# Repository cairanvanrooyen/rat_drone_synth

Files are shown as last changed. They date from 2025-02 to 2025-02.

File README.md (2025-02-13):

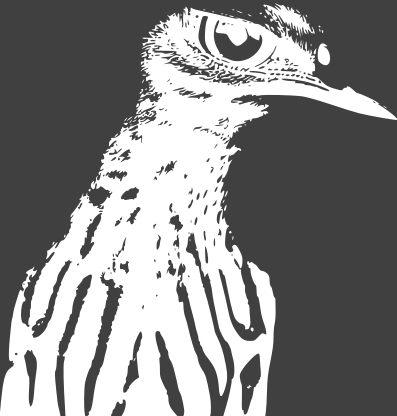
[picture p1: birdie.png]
Title


# The 'RAT' Drone Synth

This repository describes my RAT (reverse avalanche transistor) drone synth. I generated the image of the bird using Stable Diffusion (AI).

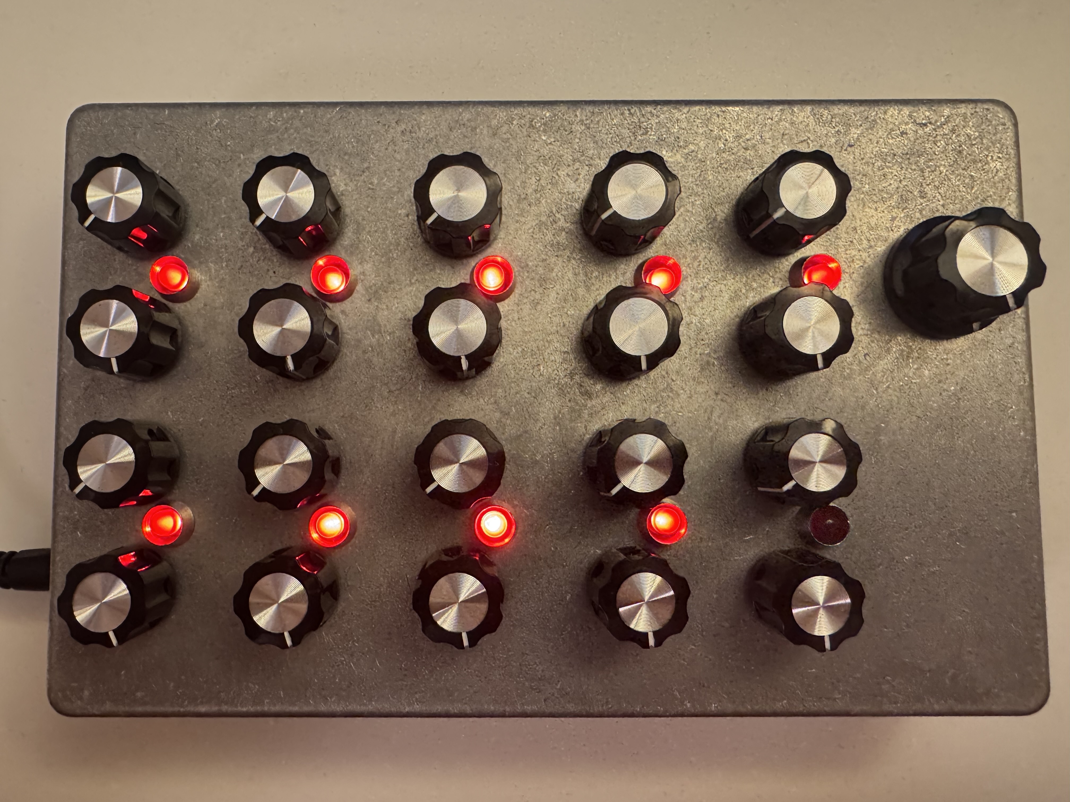
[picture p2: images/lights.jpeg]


> [!CAUTION]
> This repository is provided for information only. I am not an electronic or electrical engineer, and so, if you decide to build this project, you do so at your own risk.

## Introduction and inspiration

This project was inspired by the work by [Sam Battle](https://www.lookmumnocomputer.com/bio) of [Look Mum No Computer](https://www.lookmumnocomputer.com/). Sam released a video where he made a synthesiser from a Red Bull can - [watch it here](https://www.youtube.com/watch?v=WjrJeUBjw5g&t=1s). In his related post ['Super simple oscillator'](https://www.lookmumnocomputer.com/simplest-oscillator) he described more of the electronics and a few example schematics. There was also a link to a more technical description of reverse avalanche mode on a blog [BJT In Reverse Avalanche Mode by Kerry D. Wong](http://www.kerrywong.com/2014/03/19/bjt-in-reverse-avalanche-mode/). It was through both Sam's and Kerry's websites that I learned more about the SS9018 and became inspired to make a drone synth.

[This page by 'Pixmusix'](https://core-electronics.com.au/projects/analogue-quad-oscillator-drone-synth/) is perhaps the best I have found so far on this type of oscillator, [its history](https://www.analog.com/media/en/technical-documentation/application-notes/an72f.pdf), how it works and some nice working examples. Pix also provide a very nice animation of this circuit in action. 

## The design

My design is an adapted version of Sam Battle's ['2000 Megadrone Module'](https://www.lookmumnocomputer.com/2000-megadrone). There are schematics and a BOM on his website.

I adapted the design - removed CV, eurorack power and adapted the capacitors to generally be lower in value and therefore lower in pitch.

If you want to build this yourself, you should explore different capacitor values to suit your tastes. I chose 100uF (low), 10uF (mid) and 4.7uF (high). Although if i built another, i might include more variety.

> [!NOTE]
> Vary the capacitors according to your taste. I used 100uF, 10uF and 4.7uF - this is different to the schematic.

The design includes 10 oscillators, each with their own pitch and volume control. Finally, there is a master tone control (a kind of low pass filter). The unit is powered by a 12V DC (2.5mm) male power adaptor.

> [!WARNING]
> I messed up the potentiometer connections and so the pots work in reverse, which is kind of interesting and fits with the whole reverse theme of the synth. Some people may be annoyed or not like this - proceed at your own risk.

I designed the schematic and PCB in [KiCAD](https://www.kicad.org/) - which is incredible and its free! My schematic, PCB and drill templates are included in this repository.

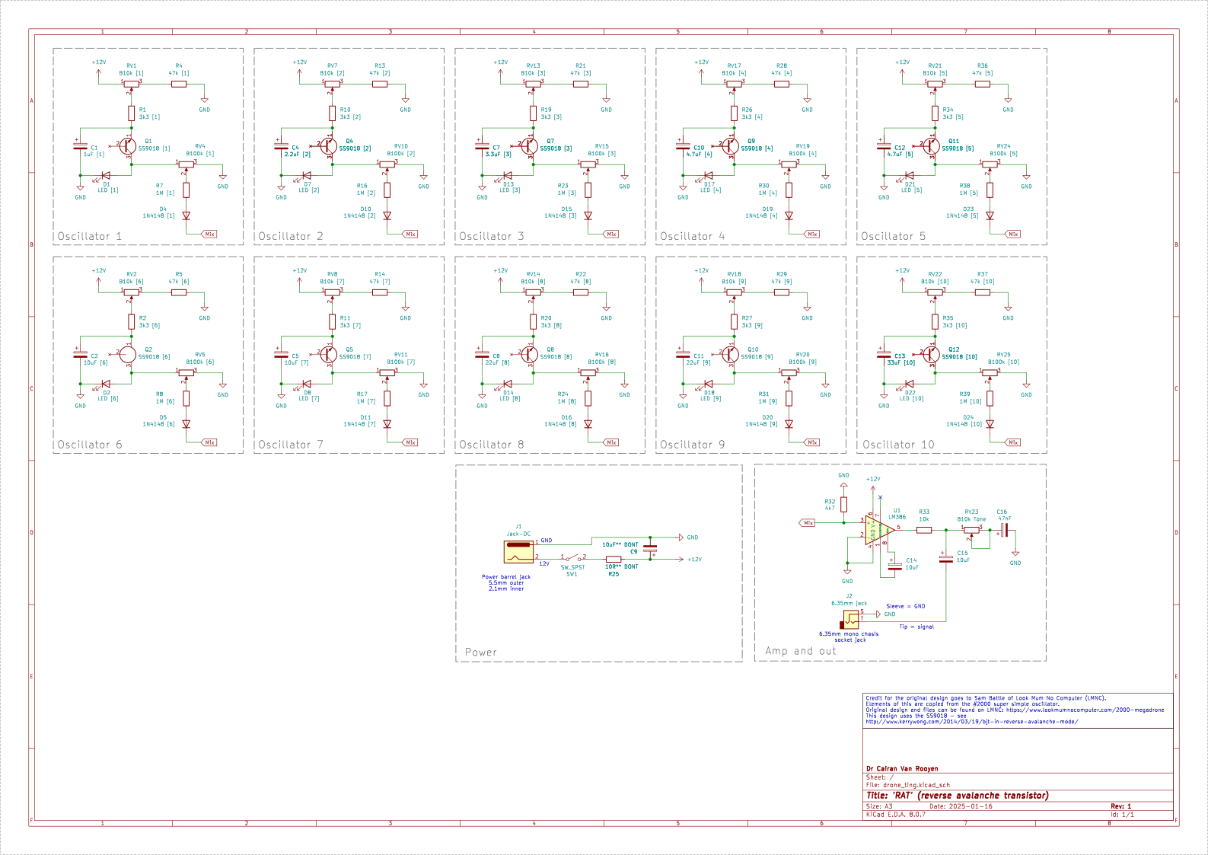
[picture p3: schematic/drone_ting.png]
Schematic


## The PCB

The PCB is simple, 2 sided with pots and LEDs on one side and all other components on the other. I had mine made by [JLCPCB](https://jlcpcb.com/), costing $11.40 + postage - for 5! If you want to order the same for yourself - navigate to the \gerbers\send_to_PCB_manufacturer.zip - simply upload this to your chosen manufacturer to order.

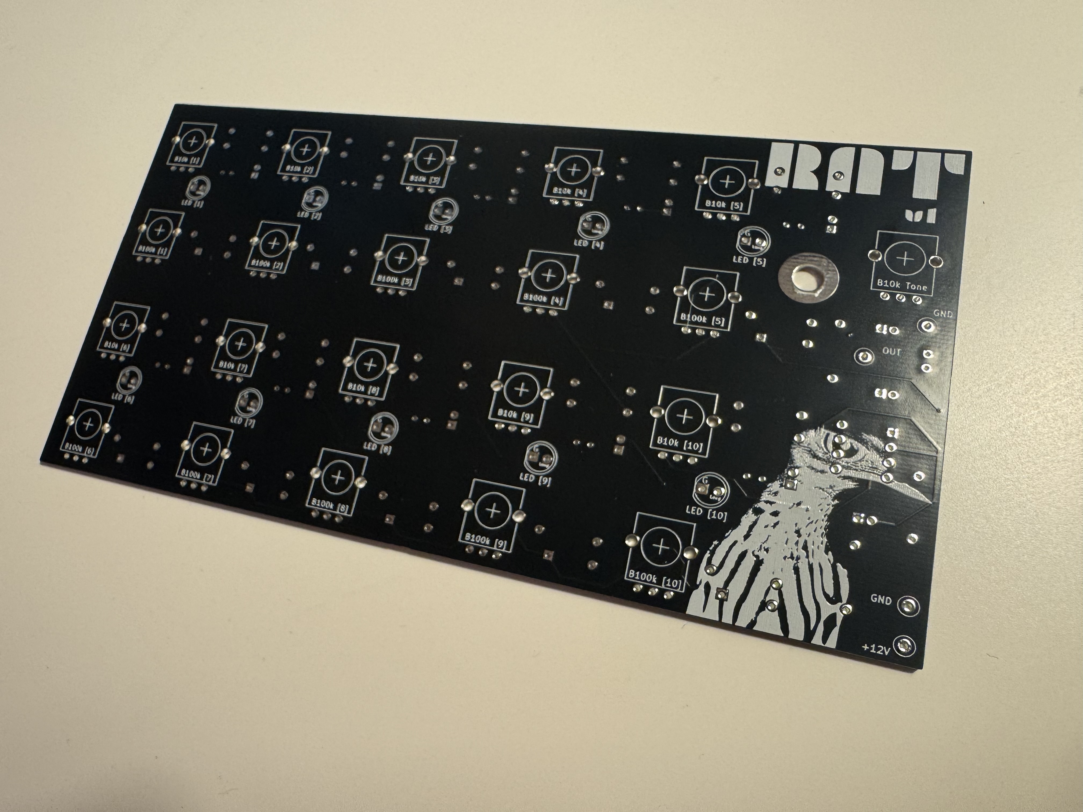
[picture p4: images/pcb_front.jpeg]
PCB front

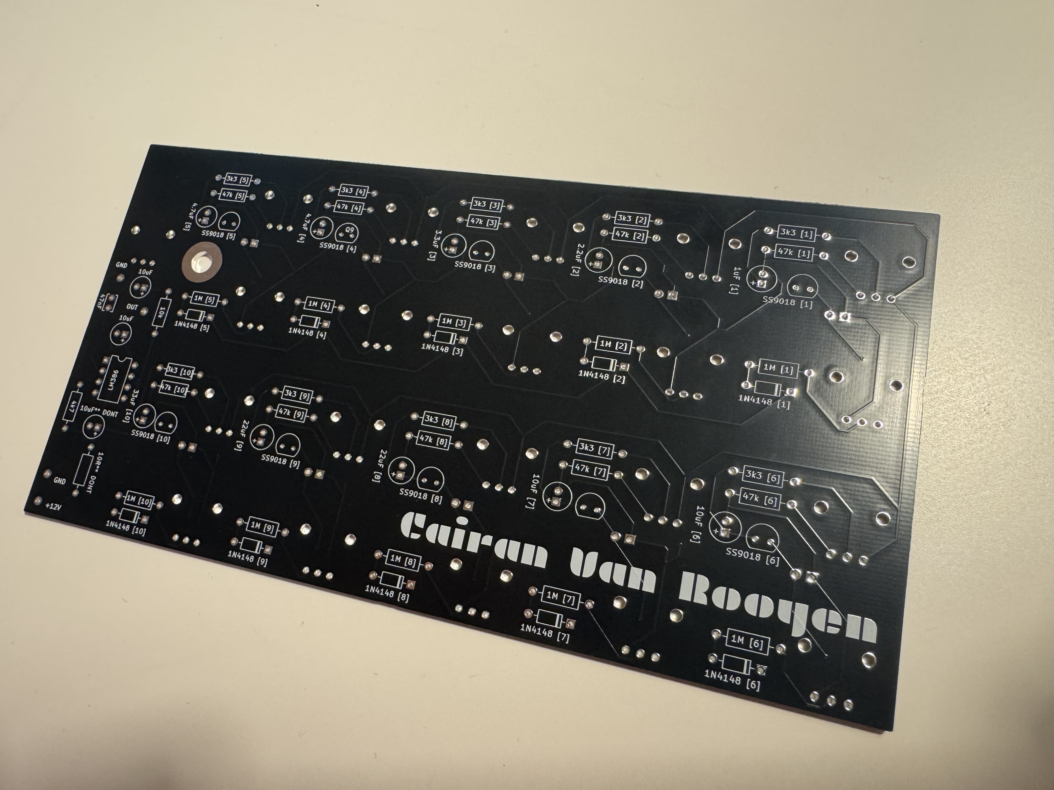
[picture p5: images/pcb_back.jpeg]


This is a very beginner friendly build, all through hole components and nothing too small.

## Bill Of Materials

I used Tayda to source all my components, apart from the 10x SS9018, which i sourced from e-Bay (£7.95 + postage).

- [Fairchild SS9018 VHF RF Bipolar Transistor](https://www.onsemi.com/download/data-sheet/pdf/ss9018-d.pdf)
- [LM386](https://www.taydaelectronics.com/lm386-audio-amplifier-1-channel-mono-class-ab-325mwx1at8-ohm-4v-12v-pdip-8.html)
- [100K OHM Linear Taper Potentiometer Round Shaft PCB 9mm](https://www.taydaelectronics.com/100k-ohm-linear-taper-potentiometer-round-shaft-pcb-9mm.html)
- [10K OHM Linear Taper Potentiometer Round Shaft PCB 9mm](https://www.taydaelectronics.com/10k-ohm-linear-taper-potentiometer-round-shaft-pcb-9mm.html)
- [KN1360 ABS Fluted Black Knob 16x12mm](https://www.taydaelectronics.com/kn1360-knob-black.html) - these are for the volume and tone knobs for each oscillator. I used a slightly larger knob for the master tone.
- [REAN Neutrik NYS229 6.35mm 1/4" Mono Chassis Socket](https://www.taydaelectronics.com/neutrik-6-35mm-1-4-mono-chassis-socket-jack.html)
- [DC Power Jack 2.5mm Panel Mount Round DC-099](https://www.taydaelectronics.com/dc-power-jack-2-5mm-x-5-5-mm-round-type-panel-mount-dc-099.html)
- [5mm Bezel LED Holder Chrome Metal](https://www.taydaelectronics.com/5mm-bezel-led-holder-chrome-metal.html)
- [LED 5mm Red Super Bright](https://www.taydaelectronics.com/led-5mm-red.html)
- Example capacitor: [10uF 50V 105C Radial Electrolytic Capacitor 5x11mm](https://www.taydaelectronics.com/10uf-50v-105c-radial-electrolytic-capacitor-5x11mm.html)
- All resistors: [1/4W 1% metal film](https://www.taydaelectronics.com/resistors/1-4w-metal-film-resistors/test-group-2.html)
- [1N4148 Switching Signal Diode](https://www.taydaelectronics.com/1n4148-switching-signal-diode.html)
- [1 small ceramic disk capacitor](https://www.taydaelectronics.com/capacitors/ceramic-disc-capacitors/test-group-2.html)

## The enclosure

I wanted an 80's industrial submarine type vibe to suit the very heavy and industrial sounds that this drone synth can produce. I opted for a [1590DD Style Aluminum Diecast Enclosure from Tayda](https://www.taydaelectronics.com/1590dd-style-aluminum-diecast-enclosure.html). I also got them to do all the [custom drilling](https://www.taydaelectronics.com/1590dd-custom-drill-enclosure-service.html) on the front. I have included the drilling template in the KiCAD files. Screenshot of this below:

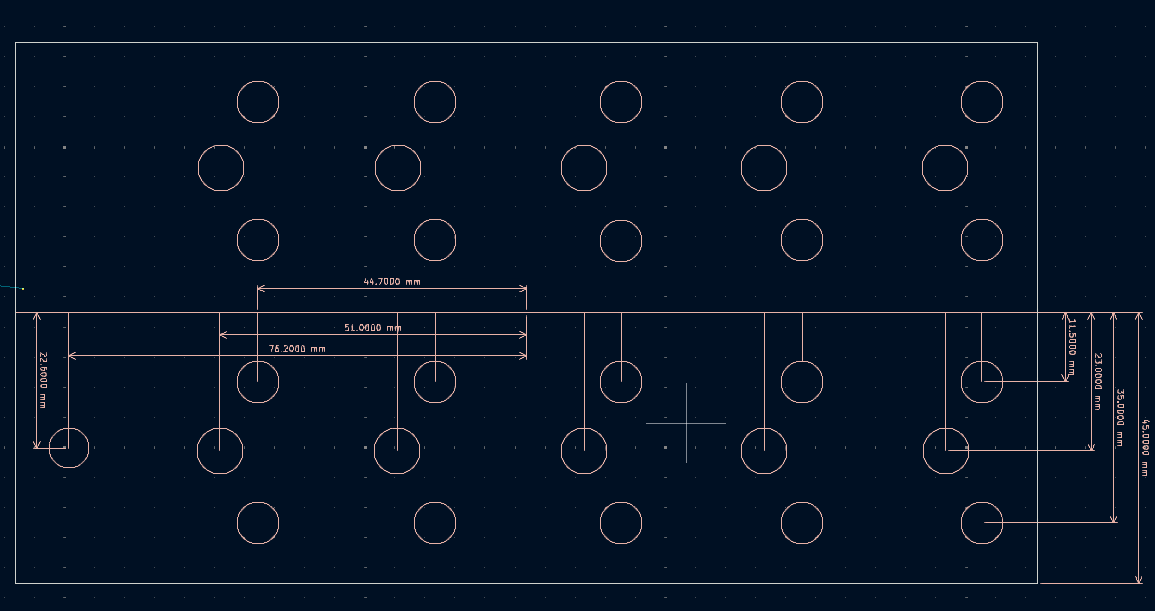
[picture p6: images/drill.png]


## The finished article

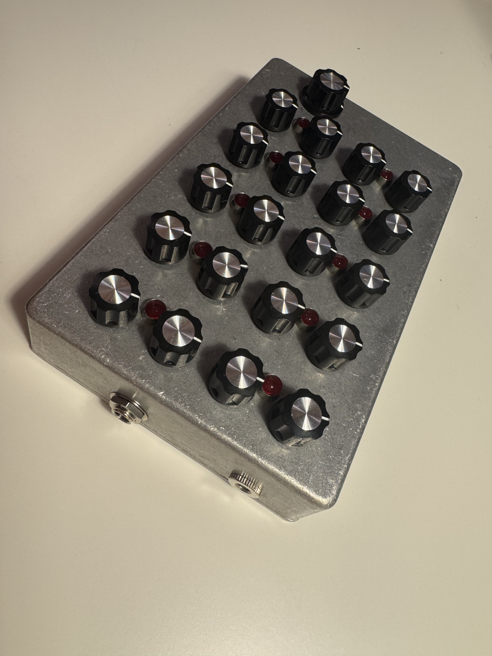
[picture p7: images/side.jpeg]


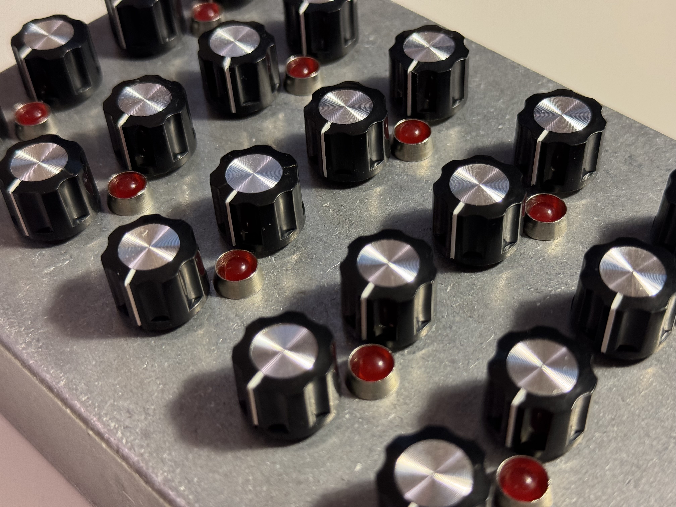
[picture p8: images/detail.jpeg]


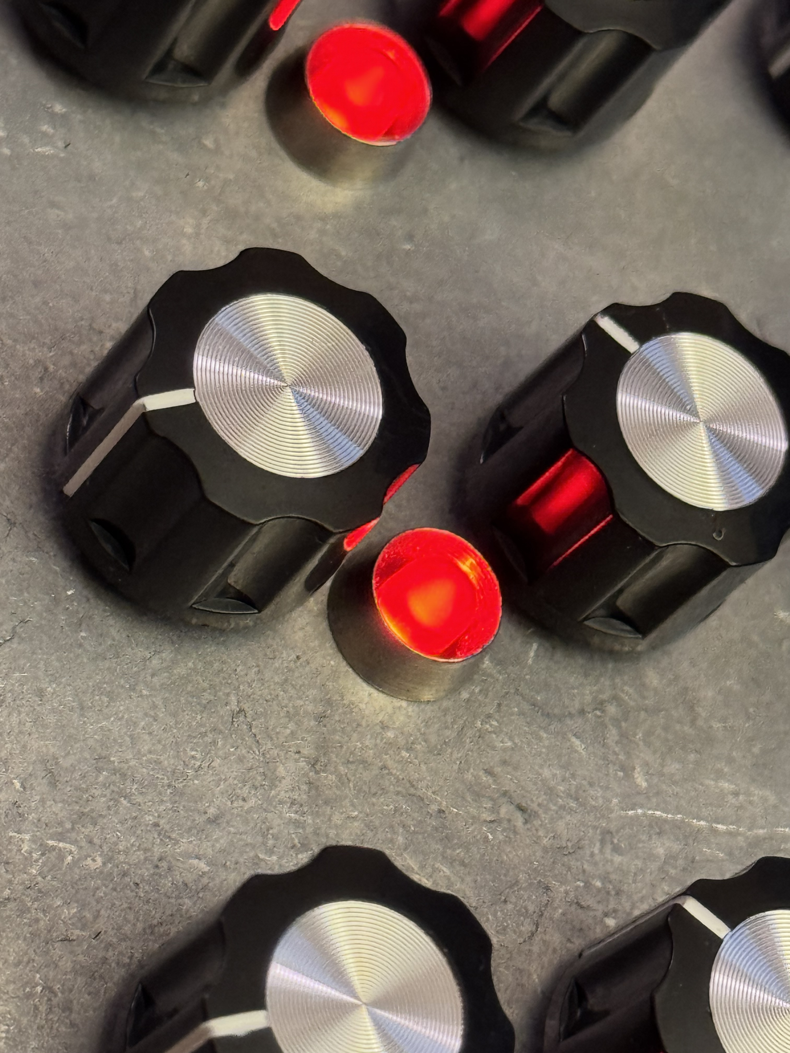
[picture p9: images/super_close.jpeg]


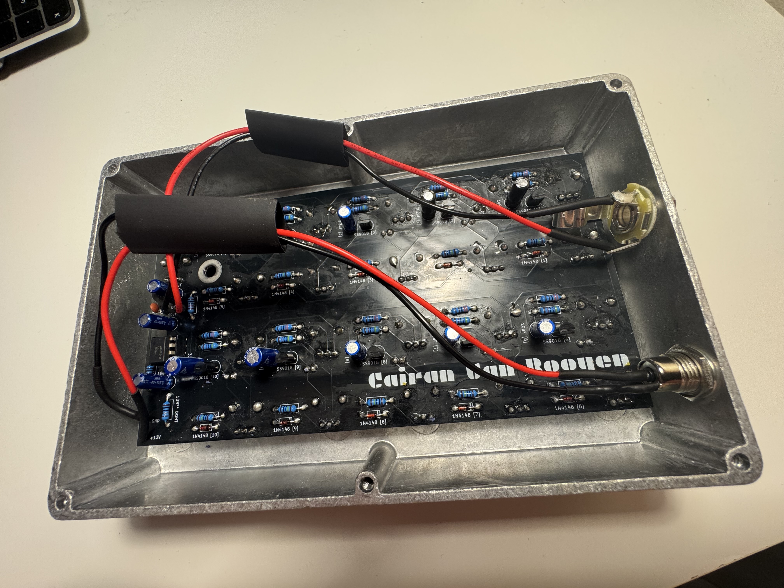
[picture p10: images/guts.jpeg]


It turned out to be exactly how I imagined. I have contemplated laser etching some labels and things onto the synth front, but I actually like the fact that its clean and blank and is intriguing. It is after all, an incredibly simple instrument to use.

## 'Technical' audio demo

Below is an image of the waveform of one 10uF oscillator. 

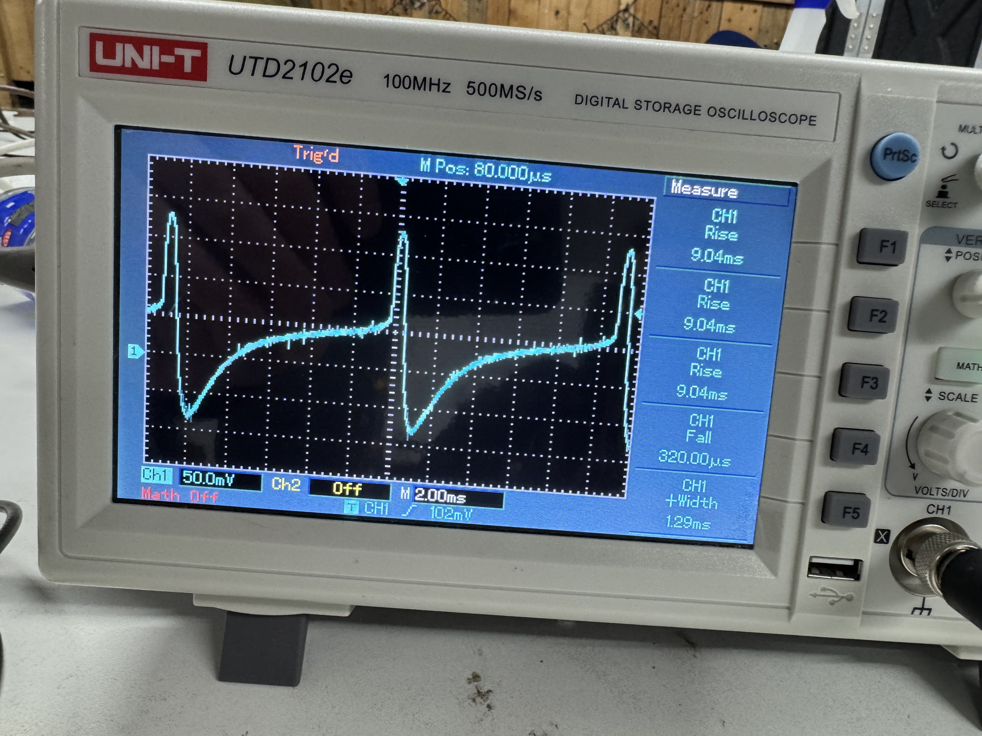
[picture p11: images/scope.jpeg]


I also recorded a video where I connected the synth to my Focusrite Scarlett Solo, passed into Ableton Live and used Pro-Q3 and [jo.Floating Oscilloscope 1.1](https://maxforlive.com/library/device/1918/jo-floating-oscilloscope) - see screenshot below. In the video, I slowly bring in each of the different (4.7uF, 10uF and 100uF oscillators) and change their volume and pitch. Pro-Q3 shows the frequency form of the sound and the oscilloscope (although not ideal) gives some idea of the waveform. The video can be accessed [here on YouTube](https://youtu.be/z13XVZWmLFw).

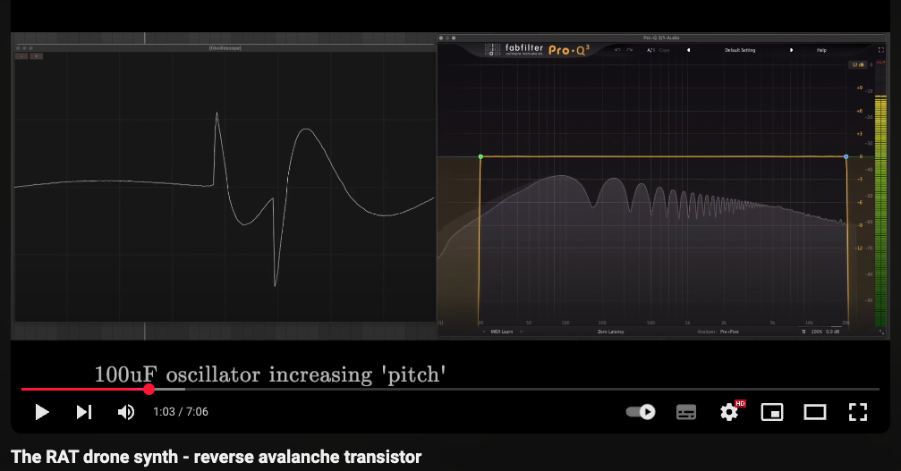
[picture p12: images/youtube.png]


## Sound demo

[Click here for sound demo](https://github.com/cairanvanrooyen/rat_drone_synth/blob/main/demo.wav)

## Lessons learned and future ideas

1. Get the pots the right way around ;)
2. Maybe have a cutout section in PCB to allow for power and audio jacks
3. More variety in capacitor values
4. Get Tayda to drill power and audio
5. Maybe laser etch the face
6. More additions: distortion, delay, wavefolder, on/off switches, CV, LFO, switching different caps and more...

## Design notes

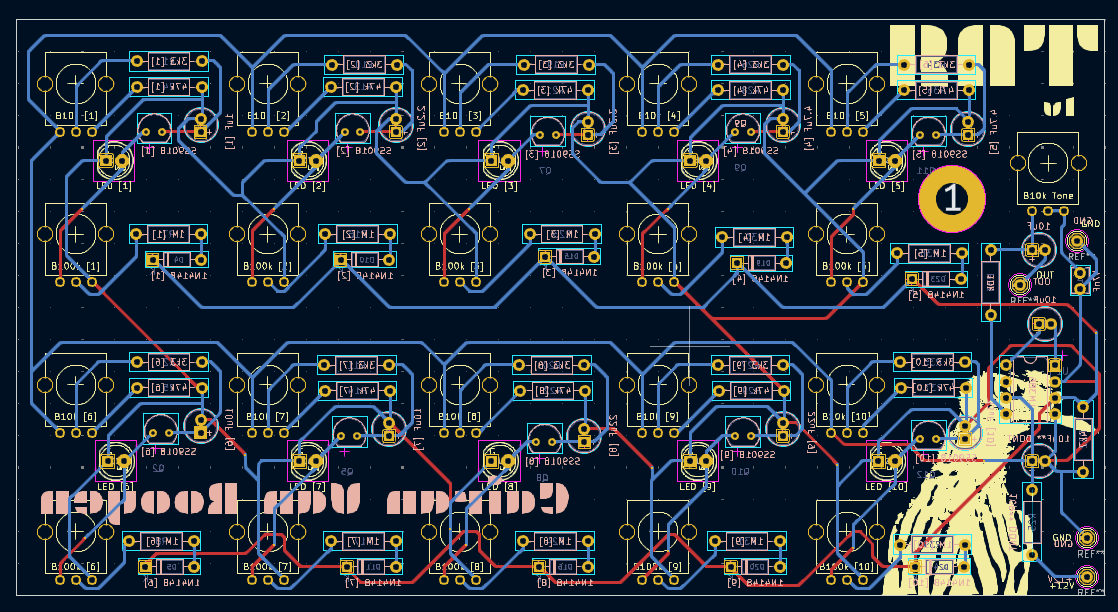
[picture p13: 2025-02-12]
images/pcb.png

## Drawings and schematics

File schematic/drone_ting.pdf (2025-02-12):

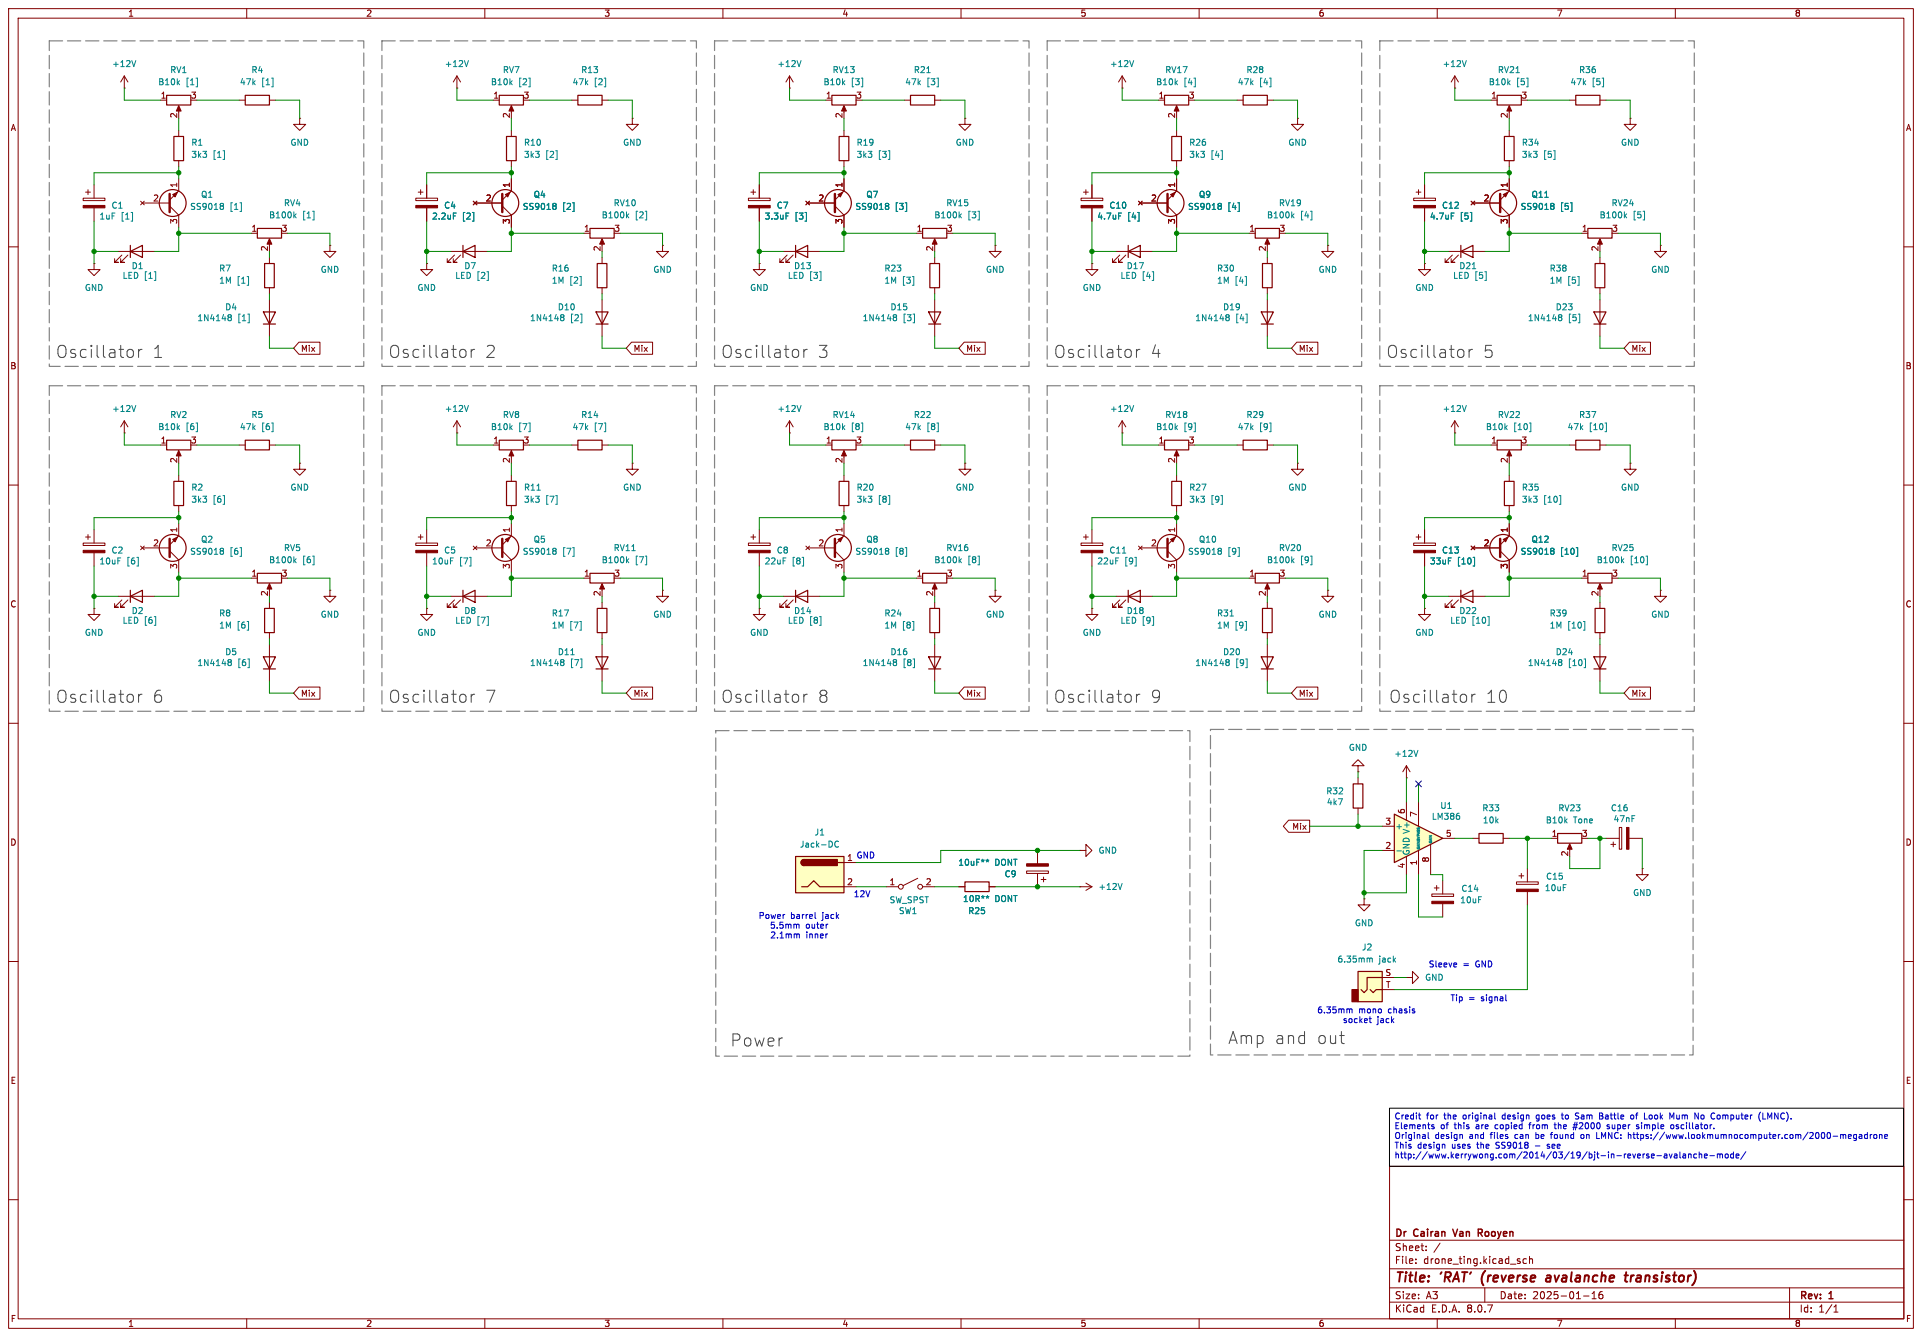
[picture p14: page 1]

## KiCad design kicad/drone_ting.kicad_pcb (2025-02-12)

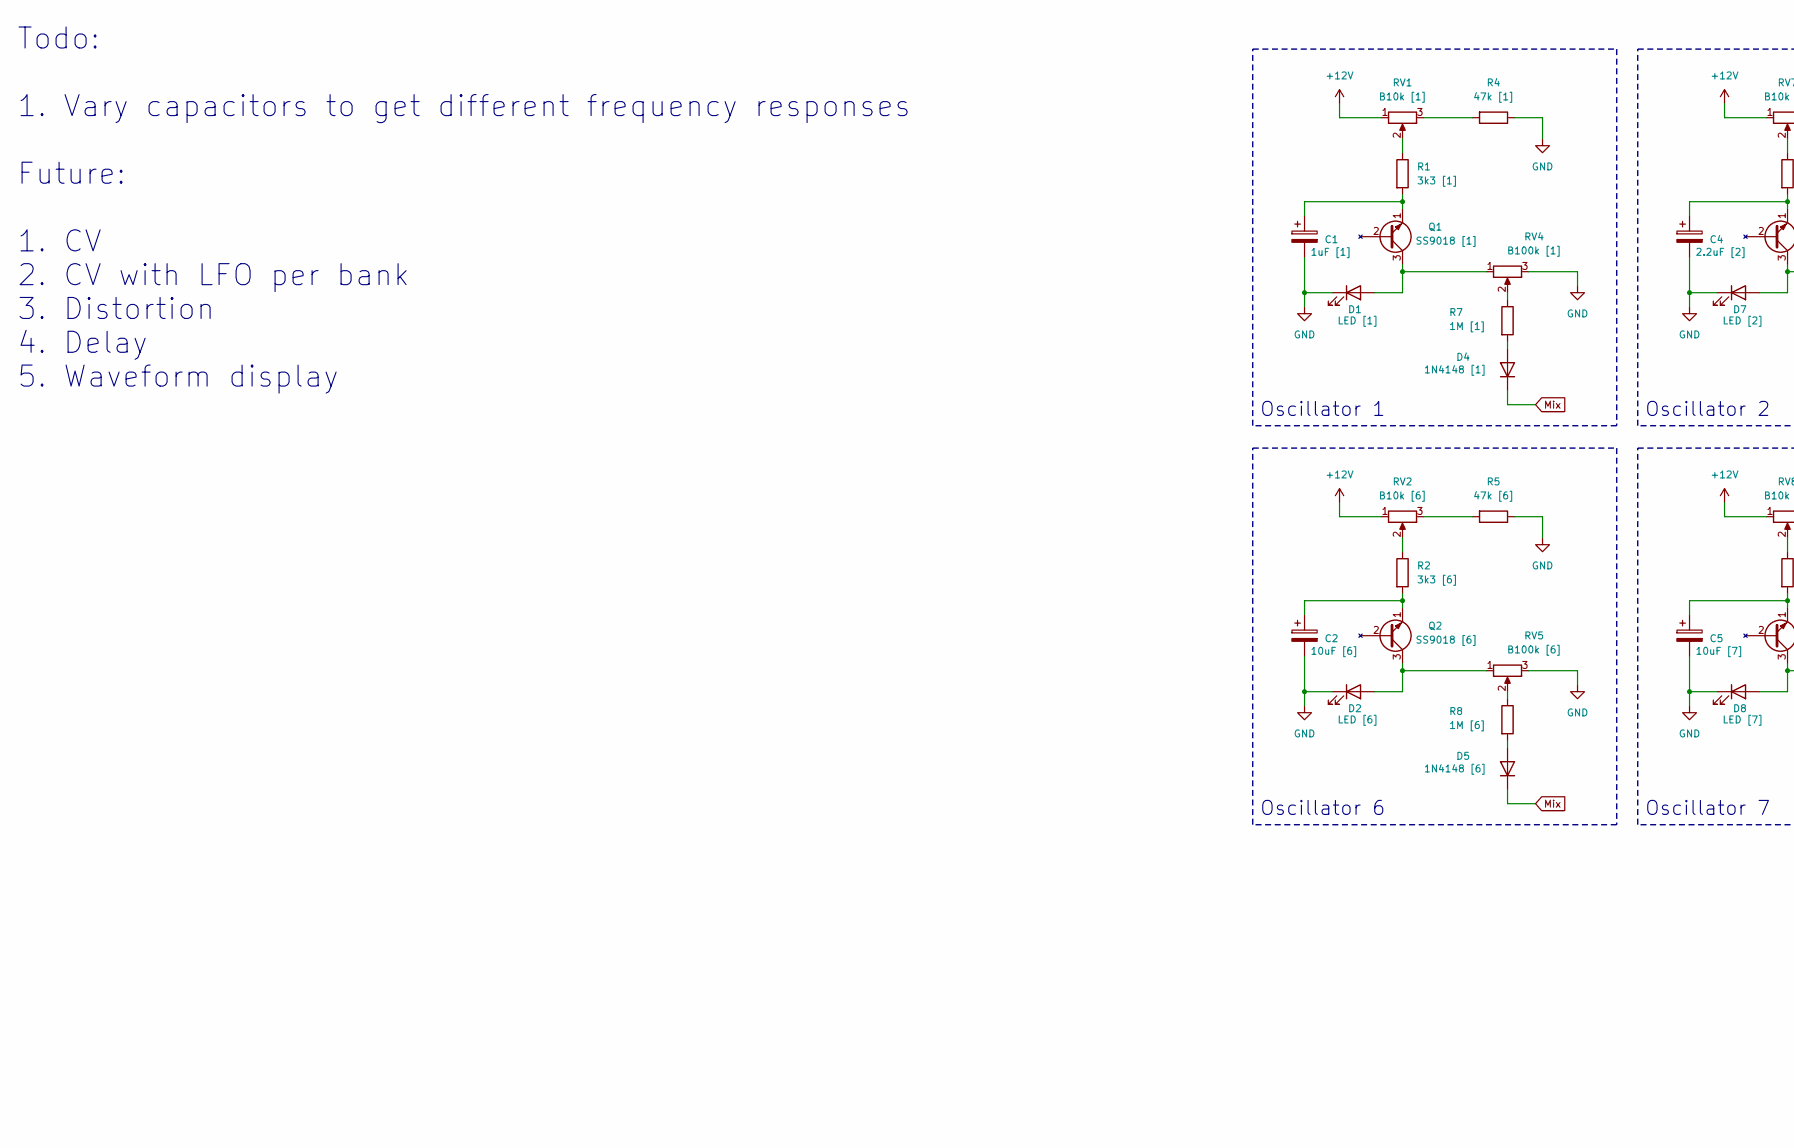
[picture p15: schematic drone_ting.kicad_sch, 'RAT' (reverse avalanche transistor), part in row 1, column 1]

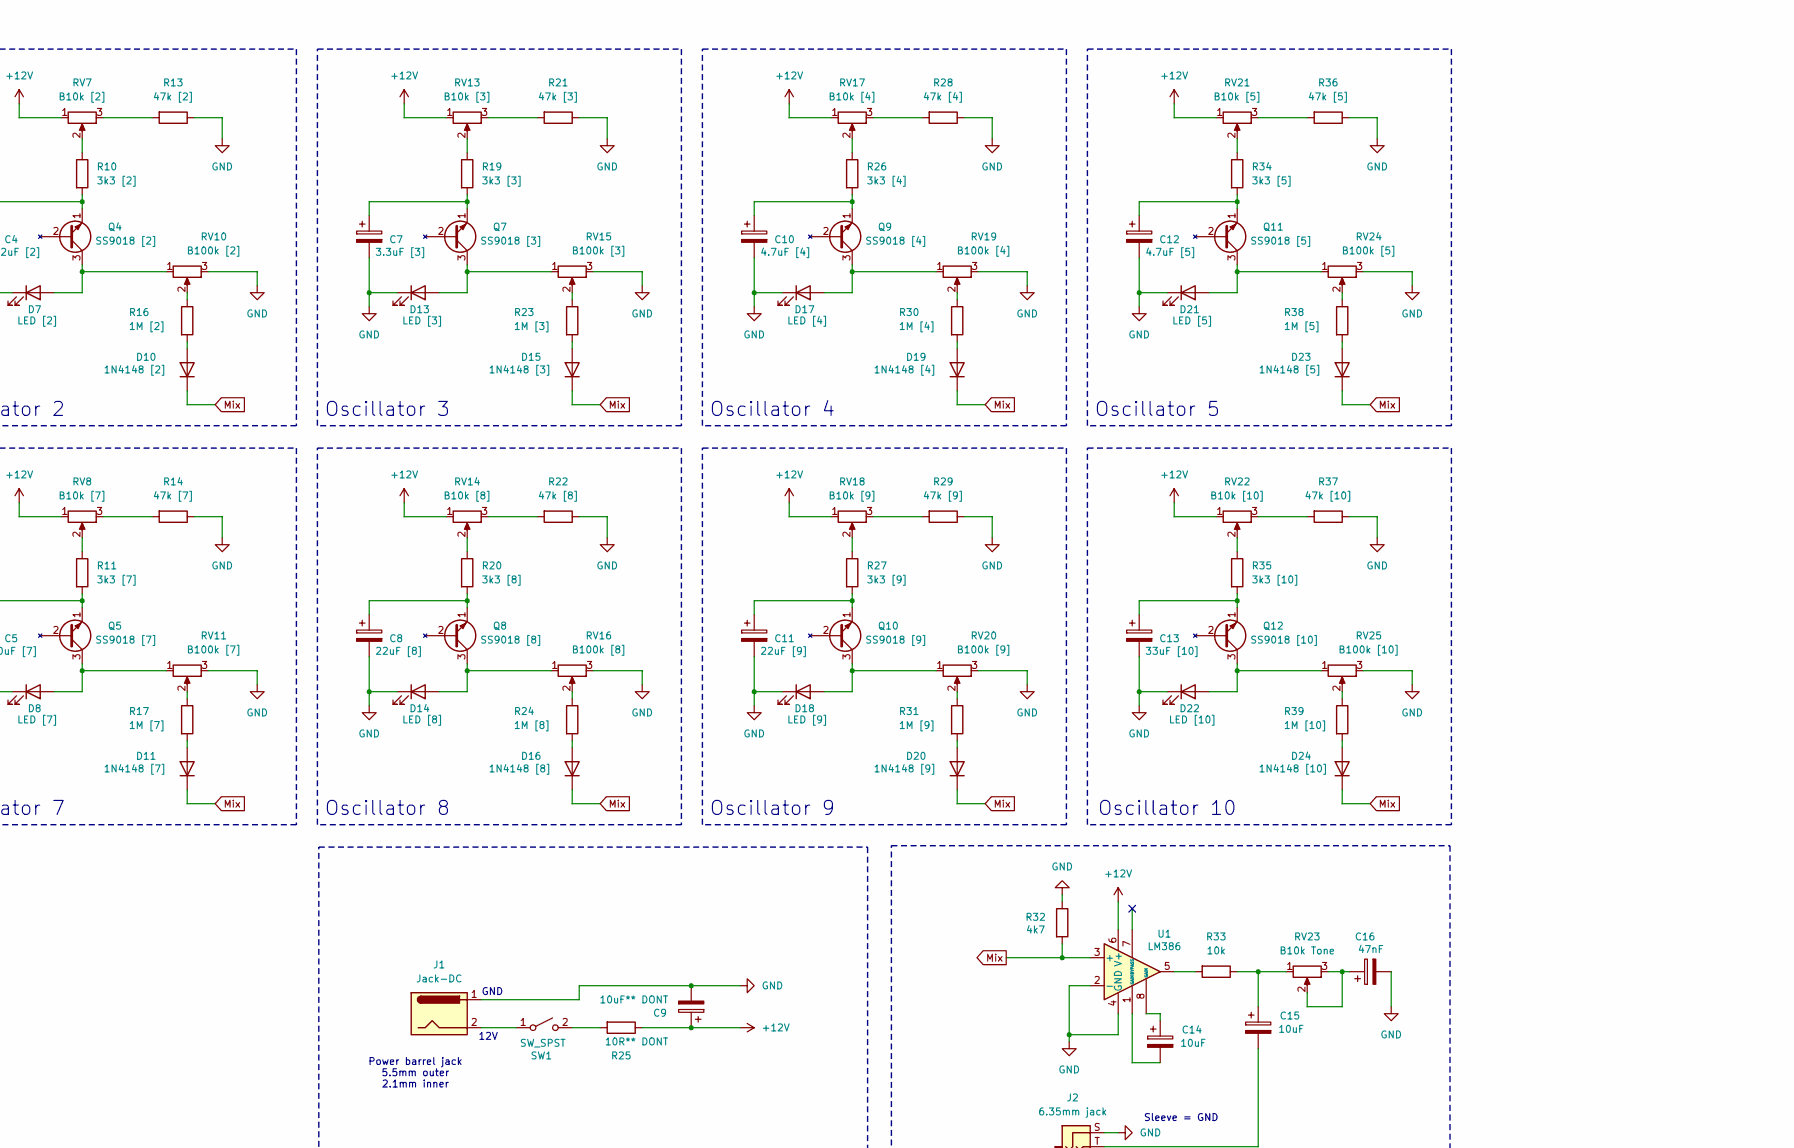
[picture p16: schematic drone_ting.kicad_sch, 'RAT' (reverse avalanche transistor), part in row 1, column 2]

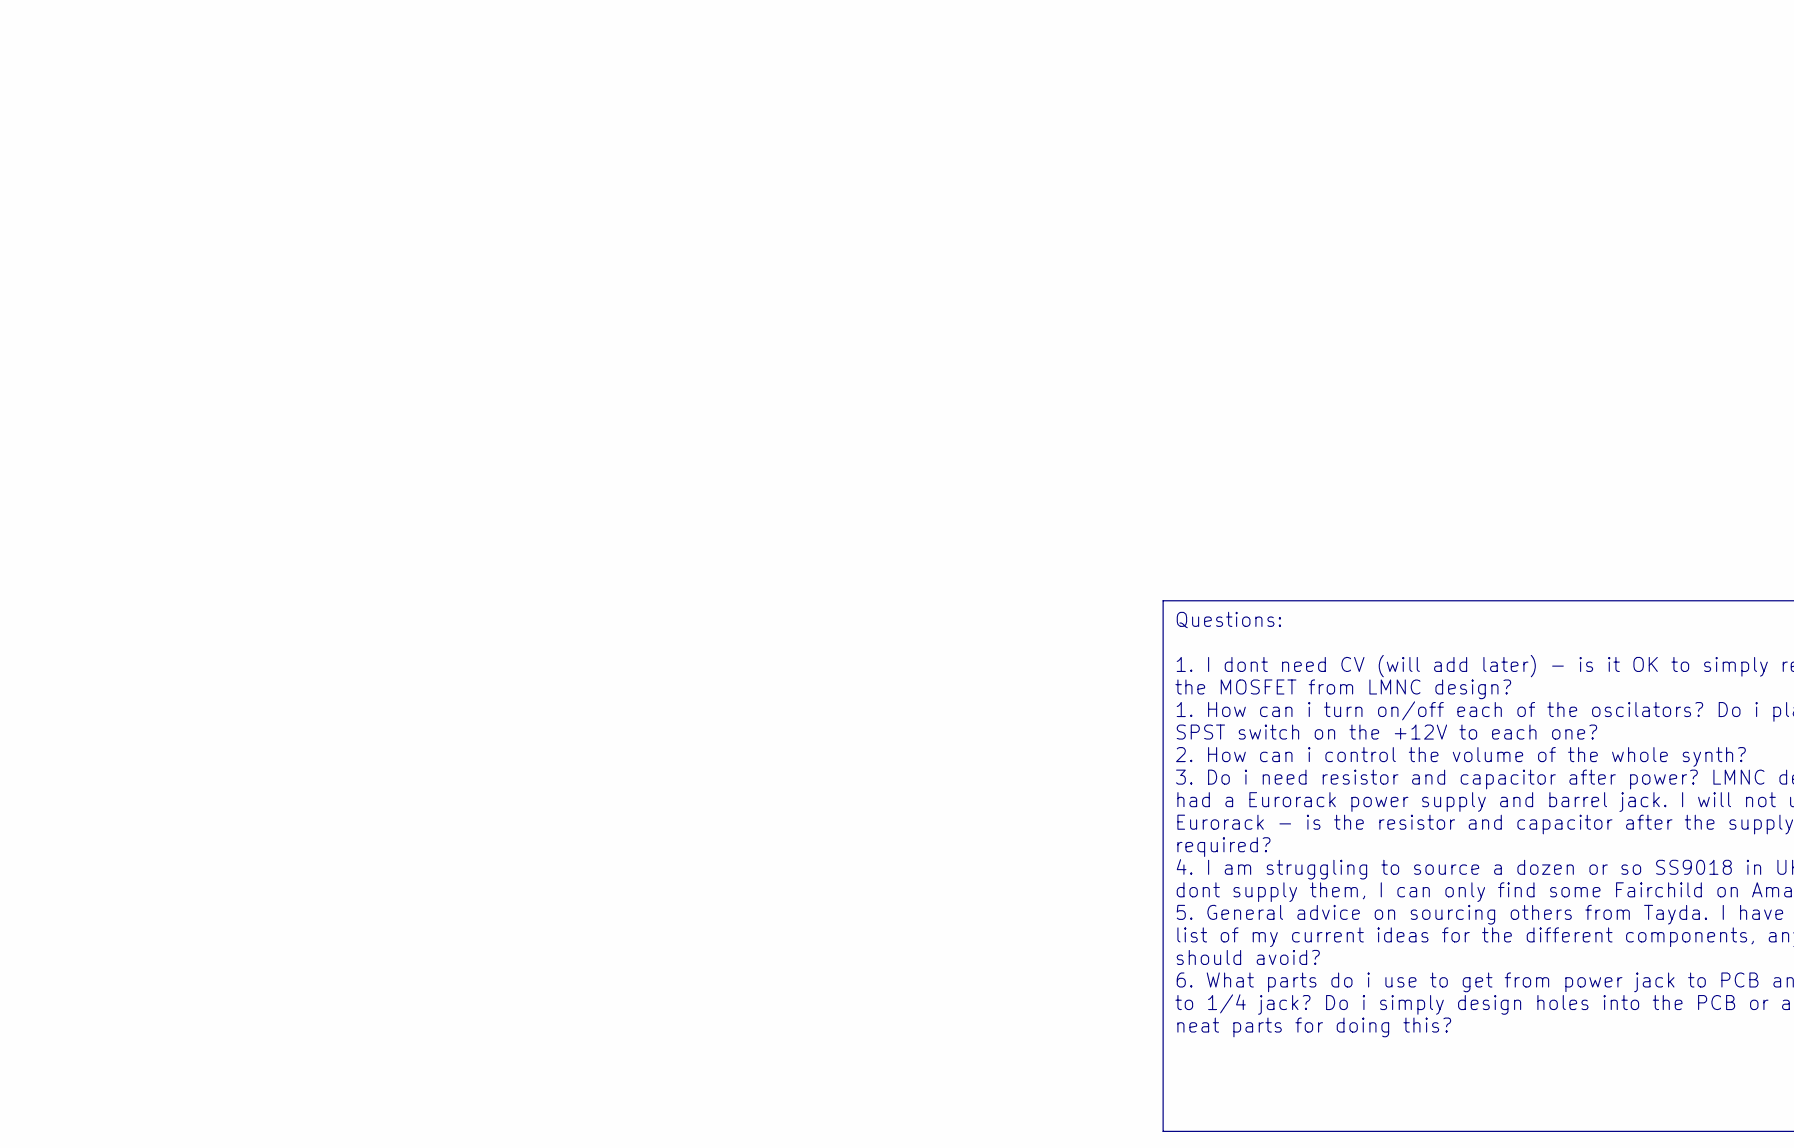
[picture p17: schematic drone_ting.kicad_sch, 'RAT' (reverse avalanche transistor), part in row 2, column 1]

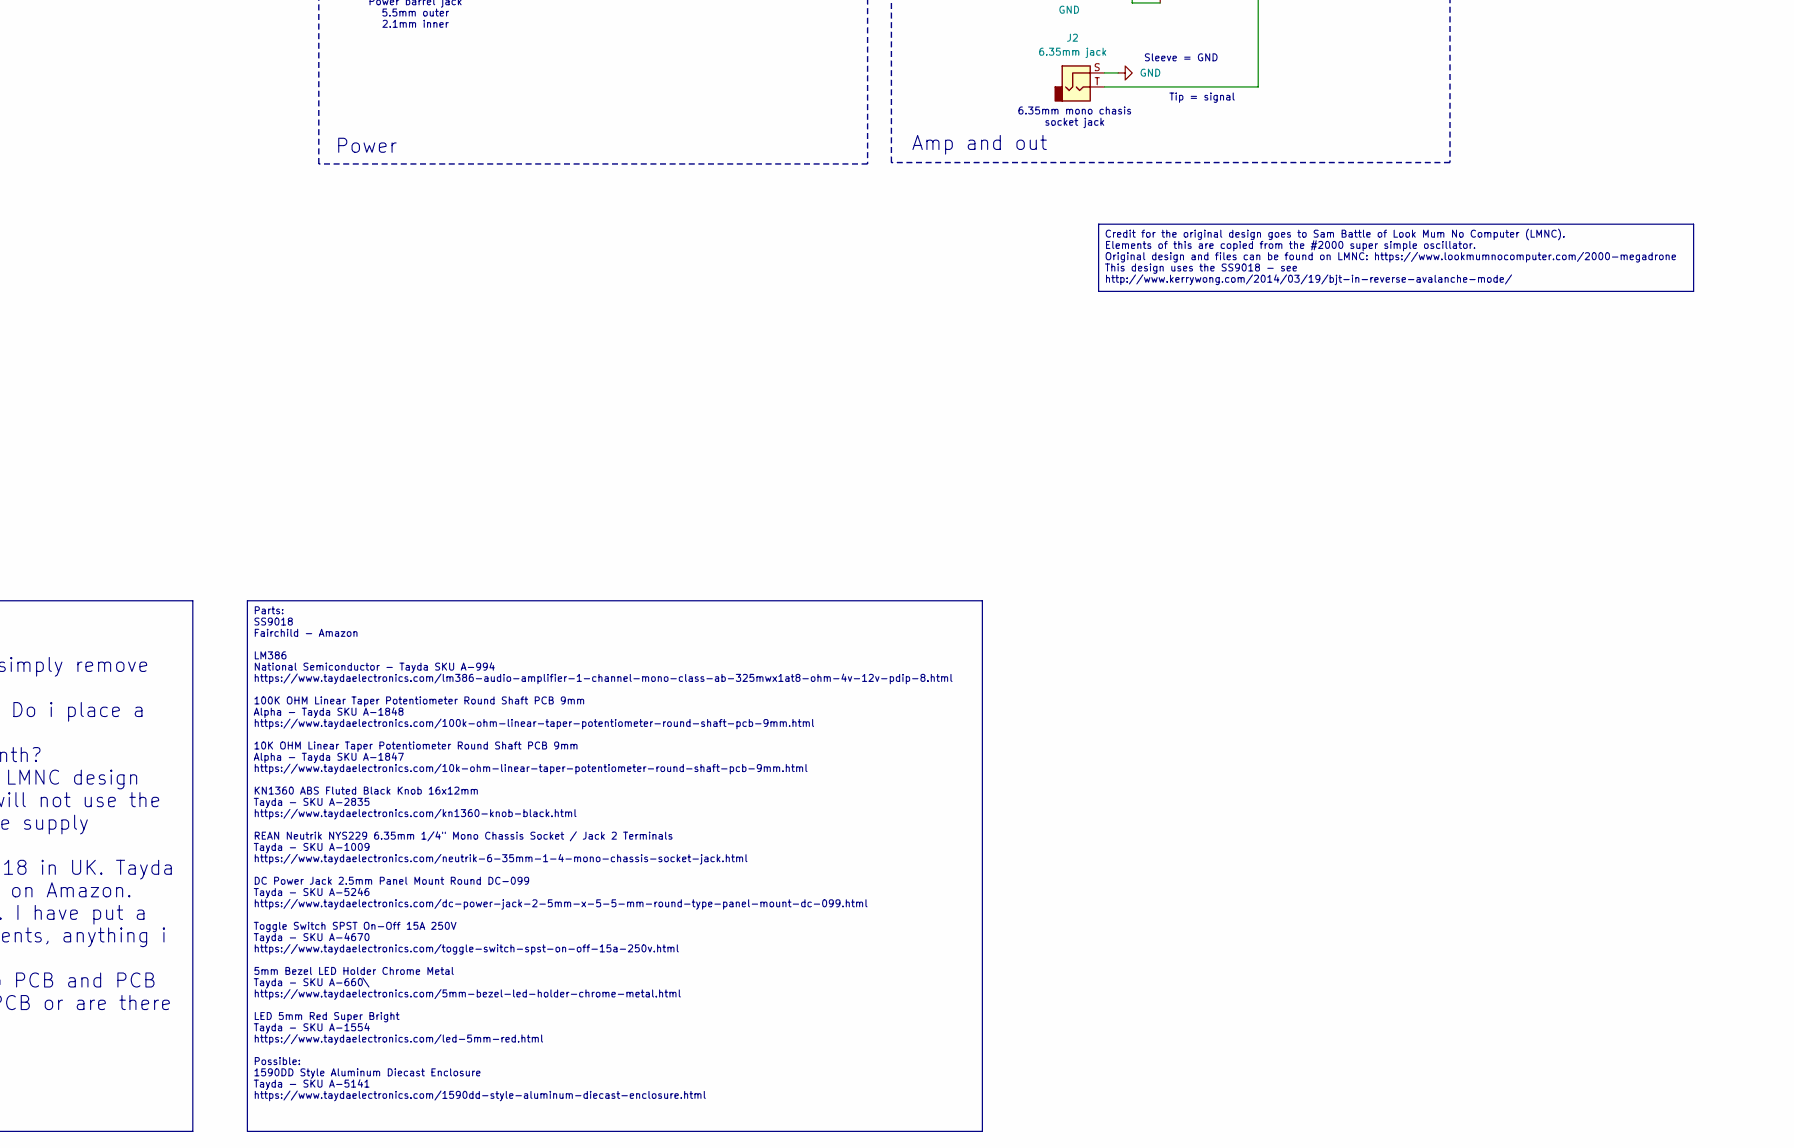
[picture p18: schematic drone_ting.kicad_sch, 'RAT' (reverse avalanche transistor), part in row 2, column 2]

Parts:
C1: 1uF [1]; C_Radial_D5.0mm_H11.0mm_P2.00mm
C2: 10uF [6]; C_Radial_D5.0mm_H11.0mm_P2.00mm
C4: 2.2uF [2]; C_Radial_D5.0mm_H11.0mm_P2.00mm
C5: 10uF [7]; C_Radial_D5.0mm_H11.0mm_P2.00mm
C7: 3.3uF [3]; C_Radial_D5.0mm_H11.0mm_P2.00mm
C8: 22uF [8]; C_Radial_D5.0mm_H11.0mm_P2.00mm
C9: 10uF** DONT; C_Radial_D5.0mm_H11.0mm_P2.00mm
C10: 4.7uF [4]; C_Radial_D5.0mm_H11.0mm_P2.00mm
C11: 22uF [9]; C_Radial_D5.0mm_H11.0mm_P2.00mm
C12: 4.7uF [5]; C_Radial_D5.0mm_H11.0mm_P2.00mm
C13: 33uF [10]; C_Radial_D5.0mm_H11.0mm_P2.00mm
C14, C15: 10uF; C_Radial_D5.0mm_H11.0mm_P2.00mm
C16: 47nF; C_Disc_D3.8mm_W2.6mm_P2.50mm
D1: LED [1]; LED_D5.0mm
D2: LED [6]; LED_D5.0mm
D4: 1N4148 [1]; D_DO-35_SOD27_P7.62mm_Horizontal
D5: 1N4148 [6]; D_DO-35_SOD27_P7.62mm_Horizontal
D7: LED [2]; LED_D5.0mm
D8: LED [7]; LED_D5.0mm
D10: 1N4148 [2]; D_DO-35_SOD27_P7.62mm_Horizontal
D11: 1N4148 [7]; D_DO-35_SOD27_P7.62mm_Horizontal
D13: LED [3]; LED_D5.0mm
D14: LED [8]; LED_D5.0mm
D15: 1N4148 [3]; D_DO-35_SOD27_P7.62mm_Horizontal
D16: 1N4148 [8]; D_DO-35_SOD27_P7.62mm_Horizontal
D17: LED [4]; LED_D5.0mm
D18: LED [9]; LED_D5.0mm
D19: 1N4148 [4]; D_DO-35_SOD27_P7.62mm_Horizontal
D20: 1N4148 [9]; D_DO-35_SOD27_P7.62mm_Horizontal
D21: LED [5]; LED_D5.0mm
D22: LED [10]; LED_D5.0mm
D23: 1N4148 [5]; D_DO-35_SOD27_P7.62mm_Horizontal
D24: 1N4148 [10]; D_DO-35_SOD27_P7.62mm_Horizontal
J1: Jack-DC; R_Axial_DIN0207_L6.3mm_D2.5mm_P10.16mm_Horizontal
J2: 6.35mm jack
Q1: SS9018 [1]; SS9018
Q2: SS9018 [6]; SS9018
Q4: SS9018 [2]; SS9018
Q5: SS9018 [7]; SS9018
Q7: SS9018 [3]; SS9018
Q8: SS9018 [8]; SS9018
Q9: SS9018 [4]; SS9018
Q10: SS9018 [9]; SS9018
Q11: SS9018 [5]; SS9018
Q12: SS9018 [10]; SS9018
R1: 3k3 [1]; R_Axial_DIN0207_L6.3mm_D2.5mm_P10.16mm_Horizontal
R2: 3k3 [6]; R_Axial_DIN0207_L6.3mm_D2.5mm_P10.16mm_Horizontal
R4: 47k [1]; R_Axial_DIN0207_L6.3mm_D2.5mm_P10.16mm_Horizontal
R5: 47k [6]; R_Axial_DIN0207_L6.3mm_D2.5mm_P10.16mm_Horizontal
R7: 1M [1]; R_Axial_DIN0207_L6.3mm_D2.5mm_P10.16mm_Horizontal
R8: 1M [6]; R_Axial_DIN0207_L6.3mm_D2.5mm_P10.16mm_Horizontal
R10: 3k3 [2]; R_Axial_DIN0207_L6.3mm_D2.5mm_P10.16mm_Horizontal
R11: 3k3 [7]; R_Axial_DIN0207_L6.3mm_D2.5mm_P10.16mm_Horizontal
R13: 47k [2]; R_Axial_DIN0207_L6.3mm_D2.5mm_P10.16mm_Horizontal
R14: 47k [7]; R_Axial_DIN0207_L6.3mm_D2.5mm_P10.16mm_Horizontal
R16: 1M [2]; R_Axial_DIN0207_L6.3mm_D2.5mm_P10.16mm_Horizontal
R17: 1M [7]; R_Axial_DIN0207_L6.3mm_D2.5mm_P10.16mm_Horizontal
R19: 3k3 [3]; R_Axial_DIN0207_L6.3mm_D2.5mm_P10.16mm_Horizontal
R20: 3k3 [8]; R_Axial_DIN0207_L6.3mm_D2.5mm_P10.16mm_Horizontal
R21: 47k [3]; R_Axial_DIN0207_L6.3mm_D2.5mm_P10.16mm_Horizontal
R22: 47k [8]; R_Axial_DIN0207_L6.3mm_D2.5mm_P10.16mm_Horizontal
R23: 1M [3]; R_Axial_DIN0207_L6.3mm_D2.5mm_P10.16mm_Horizontal
R24: 1M [8]; R_Axial_DIN0207_L6.3mm_D2.5mm_P10.16mm_Horizontal
R25: 10R** DONT; R_Axial_DIN0207_L6.3mm_D2.5mm_P10.16mm_Horizontal
R26: 3k3 [4]; R_Axial_DIN0207_L6.3mm_D2.5mm_P10.16mm_Horizontal
R27: 3k3 [9]; R_Axial_DIN0207_L6.3mm_D2.5mm_P10.16mm_Horizontal
R28: 47k [4]; R_Axial_DIN0207_L6.3mm_D2.5mm_P10.16mm_Horizontal
R29: 47k [9]; R_Axial_DIN0207_L6.3mm_D2.5mm_P10.16mm_Horizontal
R30: 1M [4]; R_Axial_DIN0207_L6.3mm_D2.5mm_P10.16mm_Horizontal
R31: 1M [9]; R_Axial_DIN0207_L6.3mm_D2.5mm_P10.16mm_Horizontal
R32: 4k7; R_Axial_DIN0207_L6.3mm_D2.5mm_P10.16mm_Horizontal
R33: 10k; R_Axial_DIN0207_L6.3mm_D2.5mm_P10.16mm_Horizontal
R34: 3k3 [5]; R_Axial_DIN0207_L6.3mm_D2.5mm_P10.16mm_Horizontal
R35: 3k3 [10]; R_Axial_DIN0207_L6.3mm_D2.5mm_P10.16mm_Horizontal
R36: 47k [5]; R_Axial_DIN0207_L6.3mm_D2.5mm_P10.16mm_Horizontal
R37: 47k [10]; R_Axial_DIN0207_L6.3mm_D2.5mm_P10.16mm_Horizontal
R38: 1M [5]; R_Axial_DIN0207_L6.3mm_D2.5mm_P10.16mm_Horizontal
R39: 1M [10]; R_Axial_DIN0207_L6.3mm_D2.5mm_P10.16mm_Horizontal
RV1: B10k [1]; Alpha9mmPot
RV2: B10k [6]; Alpha9mmPot
RV4: B100k [1]; Alpha9mmPot
RV5: B100k [6]; Alpha9mmPot
RV7: B10k [2]; Alpha9mmPot
RV8: B10k [7]; Alpha9mmPot
RV10: B100k [2]; Alpha9mmPot
RV11: B100k [7]; Alpha9mmPot
RV13: B10k [3]; Alpha9mmPot
RV14: B10k [8]; Alpha9mmPot
RV15: B100k [3]; Alpha9mmPot
RV16: B100k [8]; Alpha9mmPot
RV17: B10k [4]; Alpha9mmPot
RV18: B10k [9]; Alpha9mmPot
RV19: B100k [4]; Alpha9mmPot
RV20: B100k [9]; Alpha9mmPot
RV21: B10k [5]; Alpha9mmPot
RV22: B10k [10]; Alpha9mmPot
RV23: B10k Tone; Alpha9mmPot
RV24: B100k [5]; Alpha9mmPot
RV25: B100k [10]; Alpha9mmPot
SW1: SW_SPST
U1: LM386

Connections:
+12V: C9.1, R25.1, R25.2, RV1.1, RV2.1, RV7.1, RV8.1, RV13.1, RV14.1, RV17.1, RV18.1, RV21.1, RV22.1, SW1.2 (B), U1.6 (V+)
GND: C1.2, C2.2, C4.2, C5.2, C7.2, C8.2, C9.2, C10.2, C11.2, C12.2, C13.2, C16.2, D1.1 (K), D2.1 (K), D7.1 (K), D8.1 (K), D13.1 (K), D14.1 (K), D17.1 (K), D18.1 (K), D21.1 (K), D22.1 (K), J1.1, J2.S, R4.1, R5.1, R13.1, R14.1, R21.1, R22.1, R28.1, R29.1, R32.1, R36.1, R37.1, RV4.3, RV5.3, RV10.3, RV11.3, RV15.3, RV16.3, RV19.3, RV20.3, RV24.3, RV25.3, U1.2 (-), U1.4 (GND)
Mix: D4.1 (K), D5.1 (K), D10.1 (K), D11.1 (K), D15.1 (K), D16.1 (K), D19.1 (K), D20.1 (K), D23.1 (K), D24.1 (K), R32.2, U1.3 (+)
unnamed: C14.1, U1.8 (GAIN)
unnamed: C14.2, U1.1 (GAIN)
unnamed: C15.1, R33.1, RV23.1
unnamed: C15.2, J2.T
unnamed: C16.1, RV23.2, RV23.3
unnamed: D1.2 (A), Q1.3 (C), RV4.1
unnamed: D2.2 (A), Q2.3 (C), RV5.1
unnamed: D4.2 (A), R7.2
unnamed: D5.2 (A), R8.2
unnamed: D7.2 (A), Q4.3 (C), RV10.1
unnamed: D8.2 (A), Q5.3 (C), RV11.1
unnamed: D10.2 (A), R16.2
unnamed: D11.2 (A), R17.2
unnamed: D13.2 (A), Q7.3 (C), RV15.1
unnamed: D14.2 (A), Q8.3 (C), RV16.1
unnamed: D15.2 (A), R23.2
unnamed: D16.2 (A), R24.2
unnamed: D17.2 (A), Q9.3 (C), RV19.1
unnamed: D18.2 (A), Q10.3 (C), RV20.1
unnamed: D19.2 (A), R30.2
unnamed: D20.2 (A), R31.2
unnamed: D21.2 (A), Q11.3 (C), RV24.1
unnamed: D22.2 (A), Q12.3 (C), RV25.1
unnamed: D23.2 (A), R38.2
unnamed: D24.2 (A), R39.2
unnamed: J1.2, SW1.1 (A)
unnamed: C1.1, Q1.1 (E), R1.2
unnamed: C2.1, Q2.1 (E), R2.2
unnamed: C4.1, Q4.1 (E), R10.2
unnamed: C5.1, Q5.1 (E), R11.2
unnamed: C7.1, Q7.1 (E), R19.2
unnamed: C8.1, Q8.1 (E), R20.2
unnamed: C10.1, Q9.1 (E), R26.2
unnamed: C11.1, Q10.1 (E), R27.2
unnamed: C12.1, Q11.1 (E), R34.2
unnamed: C13.1, Q12.1 (E), R35.2
unnamed: R1.1, RV1.2
unnamed: R2.1, RV2.2
unnamed: R4.2, RV1.3
unnamed: R5.2, RV2.3
unnamed: R7.1, RV4.2
unnamed: R8.1, RV5.2
unnamed: R10.1, RV7.2
unnamed: R11.1, RV8.2
unnamed: R13.2, RV7.3
unnamed: R14.2, RV8.3
unnamed: R16.1, RV10.2
unnamed: R17.1, RV11.2
unnamed: R19.1, RV13.2
unnamed: R20.1, RV14.2
unnamed: R21.2, RV13.3
unnamed: R22.2, RV14.3
unnamed: R23.1, RV15.2
unnamed: R24.1, RV16.2
unnamed: R26.1, RV17.2
unnamed: R27.1, RV18.2
unnamed: R28.2, RV17.3
unnamed: R29.2, RV18.3
unnamed: R30.1, RV19.2
unnamed: R31.1, RV20.2
unnamed: R33.2, U1.5
unnamed: R34.1, RV21.2
unnamed: R35.1, RV22.2
unnamed: R36.2, RV21.3
unnamed: R37.2, RV22.3
unnamed: R38.1, RV24.2
unnamed: R39.1, RV25.2

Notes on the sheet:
Credit for the original design goes to Sam Battle of Look Mum No Computer (LMNC). Elements of this are copied from the #2000 super simple oscillator. Original design and files can be found on LMNC: https://www.lookmumnocomputer.com/2000-megadrone This design uses the SS9018 - see http://www.kerrywo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
Questions: 1. I dont need CV (will add later) - is it OK to simply remove the MOSFET from LMNC design? 1. How can i turn on/off each of the oscilators? Do i place a SPST switch on the +12V to each one? 2. How can i control the volume of the whole synth? 3. Do i need resistor and capacitor after pow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
Parts: SS9018 Fairchild - Amazon LM386 National Semiconductor - Tayda SKU A-994 https://www.taydaelectronics.com/lm386-audio-amplifier-1-channel-mono-class-ab-325mwx1at8-ohm-4v-12v-pdip-8.html 100K OHM Linear Taper Potentiometer Round Shaft PCB 9mm Alpha - Tayda SKU A-1848 https://www.taydaelectron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
Oscillator 5
Tip = signal
Power
Oscillator 4
Sleeve = GND
Oscillator 8
Oscillator 7
GND
Amp and out
Oscillator 6
Oscillator 9
Oscillator 2
Oscillator 1
12V
Todo: 1. Vary capacitors to get different frequency responses Future: 1. CV 2. CV with LFO per bank 3. Distortion 4. Delay 5. Waveform display
Oscillator 3
Oscillator 10
Power barrel jack 5.5mm outer 2.1mm inner
6.35mm mono chasis socket jack

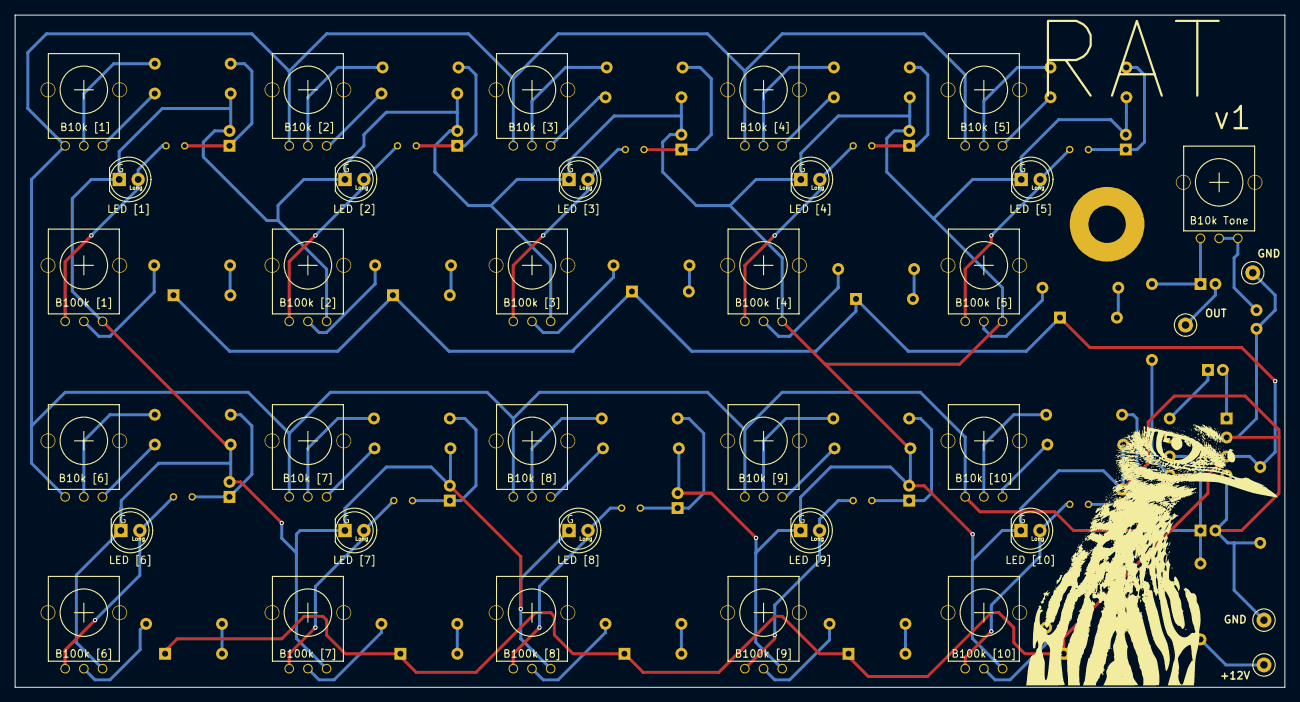
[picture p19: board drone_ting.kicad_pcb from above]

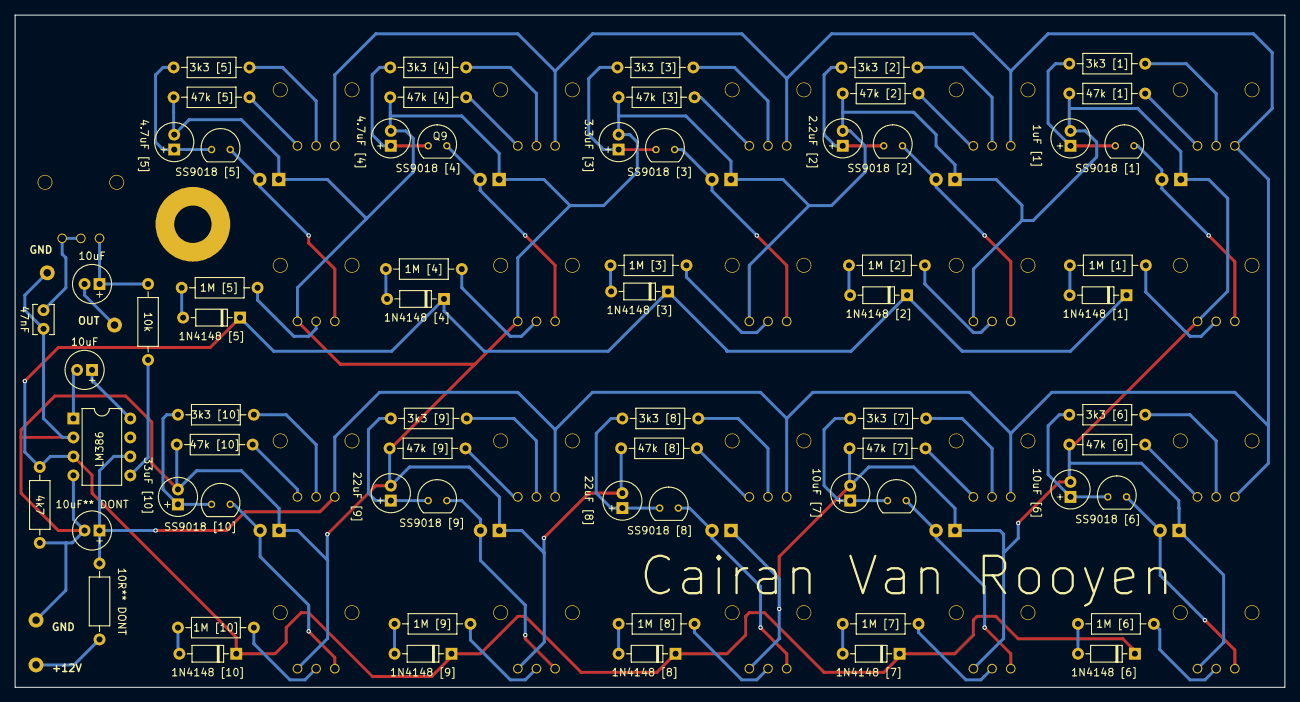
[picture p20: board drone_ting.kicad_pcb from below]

Board: 2 copper layers, 170.0 x 90.0 mm, 99 parts (68 on the bottom side), 68 nets.
